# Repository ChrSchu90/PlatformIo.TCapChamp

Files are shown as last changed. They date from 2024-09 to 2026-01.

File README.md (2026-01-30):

# PlatformIo.TCapChamp


## Description
`ESP32` project that manipulates the outdoor air temperature measurement to adjust the heat pump cycle rate. In case the heat pump is over dimensioned it can increase its efficiency dramatically since you can adjust the cycle rate specifically on your environment and needs.
The manipulated temperature output needs to be connected to the external temperature sensor of the T-Cap.

If you already use an external temperature sensor you can connect it as input sensor for the ESP, in case you don't have a temperature sensor you can use the free [OpenWeather API](https://api.openweathermap.org) to receive actual temperatures. 

Via an optional 0-10V DAC it is also possible to limit the power consumption via `Demand Control` of the T-Cap.

> [!NOTE]
> You can find the measurements, charts and calculations inside the [TestsAndCharts.xlsx](Documentation/TestsAndCharts.xlsx),
> device specific information can be taken from the [T-Cap Service Manual (PDF)](https://web.archive.org/web/20250917183120/https://www.kaelte-bast.de/dateien_neu13/Panasonic/01-produktunterlagen/aquarea/produkte/waermepumpen/t-cap/sqc/handbuch_e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)

> [!TIP]
> Most important Manual pages:
> - 49 Wiring Connection Diagram
> - 53 Electronic Circuit Diagram
> - 56 Main Circuit Board 
> - 57 Sub Printed Circuit Board
> - 76 Cable management
> - 78 Temperature Sensor
> - 88 Demand Control
> - 128 Alternative Outdoor Ambient Sensor Control

> [!Caution]
> The connection between the T-Cap and the Controller should only be done by a trained professional. 
> **There is a danger to life due to high voltage (230V/400V) within the device!**

## Features
| Feature | Completed |
| --- | --- |
| Automatic switch between WiFi AP and Client mode | &#10003;  |
| Hardware sensor for input temperature | &#10003;  |
| Weather API for input temperature (OpenWeather) | &#10003;  |
| 0V-10V Demand control (Requires optional board) | &#10003;  |
| OTA Updates | &#10003;  |
| Captive Portal (if not working use IP `192.168.4.1`) | &#10003;  |
| Custom webinterface for better accessibility | &#10007;  |

## Bill of Material & Tools
| Name | Required | Description |
| --- | --- | --- |
| [ESP32 NodeMCU-32S](https://www.amazon.de/dp/B0CQSWC67G) | &#10003; | Microcontroller |
| [MCP4151-503E/P](https://agelektronik.de/digital-potentiometer/6459-mcp4151-503ep-digital-potentiometer50k256-steps1-kanalspidip-8.html) | &#10003; | Digital Potentiometer 50K, 256 steps, SPI |
| [Electrical wire 0.5mm² 20awg](https://www.amazon.de/dp/B08BZKR22W) | &#10003; | For bridges on custom Controller board |
| [Electrical wire 0.5mm² 20awg](https://www.amazon.de/dp/B0BJKHBW2Z) | &#10003; | For connection between bords and relay |
| [Electrical wire 18awg 2×0.75mm²](https://www.amazon.de/dp/B0B7WSMR8L) | &#10007; | Connection optional 0-10V Demand Control to T-Cap |
| [Electrical wire 18awg 4×0.75mm²](https://www.amazon.de/dp/B0BFWL2RZB) | &#10003; | Connection temperature output to T-Cap |
| [Prototype Board](https://www.amazon.de/dp/B08F2TS7ZC) | &#10003; | For final board |
| 10k resistor | &#10003; | Voltage divider for input sensor |
| 5k resistor | &#10003; | Pre-Resistor for Digital potentiometer (defines the possible output temperature, in my case +30°C to -20°C) |
| 2k resistor | &#10003; | GND pulldown for unused Digital potentiometer terminal |
| [4CH 5V Relay Module](https://www.amazon.de/dp/B09FS5G1Y9) | &#10007; | Optional relay module (High-Level-Trigger) for fallback implementation, not required but highly recommended!  |
| [DFRobot Gravity I2C DAC Module](https://www.dfrobot.com/product-2613.html) | &#10007; | Optional I2C DAC 0-10V for Demand Control |
| [Breadboard Kit](https://www.amazon.de/dp/B0B18G3V5T) | &#10007; | Prototype Board for testing |
| [Connectors](https://www.amazon.de/dp/B087RN8FDZ) | &#10007; | Connector for wires |
| [Socket for ESP](https://www.amazon.de/dp/B07DBY753C) | &#10007; | Socket for ESP |
| [IC Sockets](https://www.amazon.de/dp/B01GOLSUAU) | &#10007; | IC Socket for MCP4151 |

### Housing (example)
| Name | Description |
| --- | --- |
| [Housing](https://www.amazon.de/dp/B0CKT697NP) | Housing for Controller, Relay... |
| [USB-C Connector](https://www.amazon.de/dp/B0BQGBWVWM) | USB connector for power or PC |
| [4-Pin Connector Temperature](https://www.amazon.de/dp/B07TJK2Z7M) | Connector for temperature input/output  |
| [2-Pin Connector Demand Control](https://www.amazon.de/dp/B07JMYCPSN) | Connector for Demand control (optional) |
| [Mount for boards](https://www.amazon.de/dp/B09C21MS45) | Connector for Demand control (optional) |
| [Power Supply (USB-C)](https://www.amazon.de/dp/B07TMPC9FG) | External USB-C power supply |

### Tools
- Soldering iron, Solder...
- Multimeter
- Drill (for housing)
- Glue (for housing board mounts)

## Electrical Drawings
You can find the electrical drawings and parts inside `Documentation\Fritzing` as [Fritzing](https://fritzing.org/) (freeware) project.

### Without failover relay
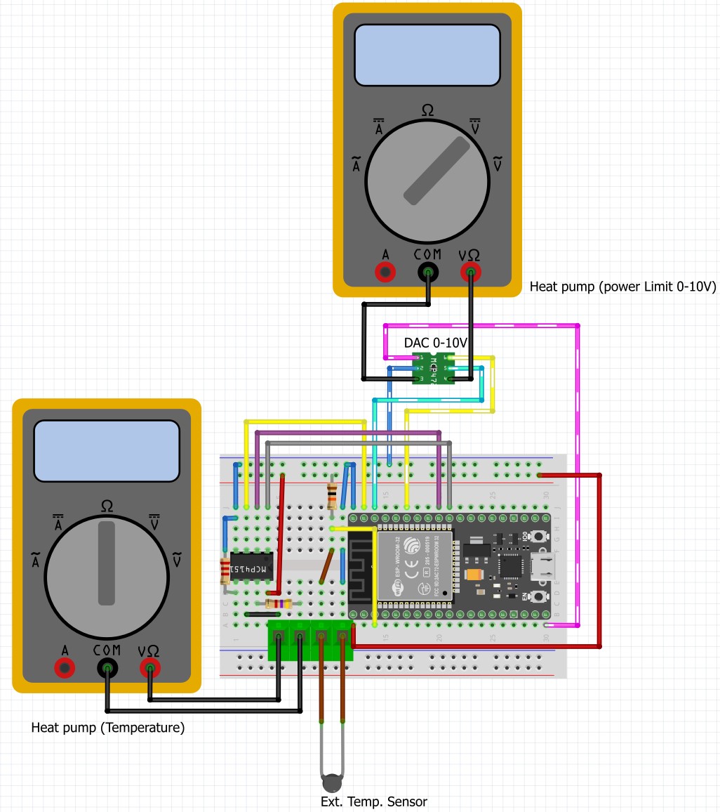
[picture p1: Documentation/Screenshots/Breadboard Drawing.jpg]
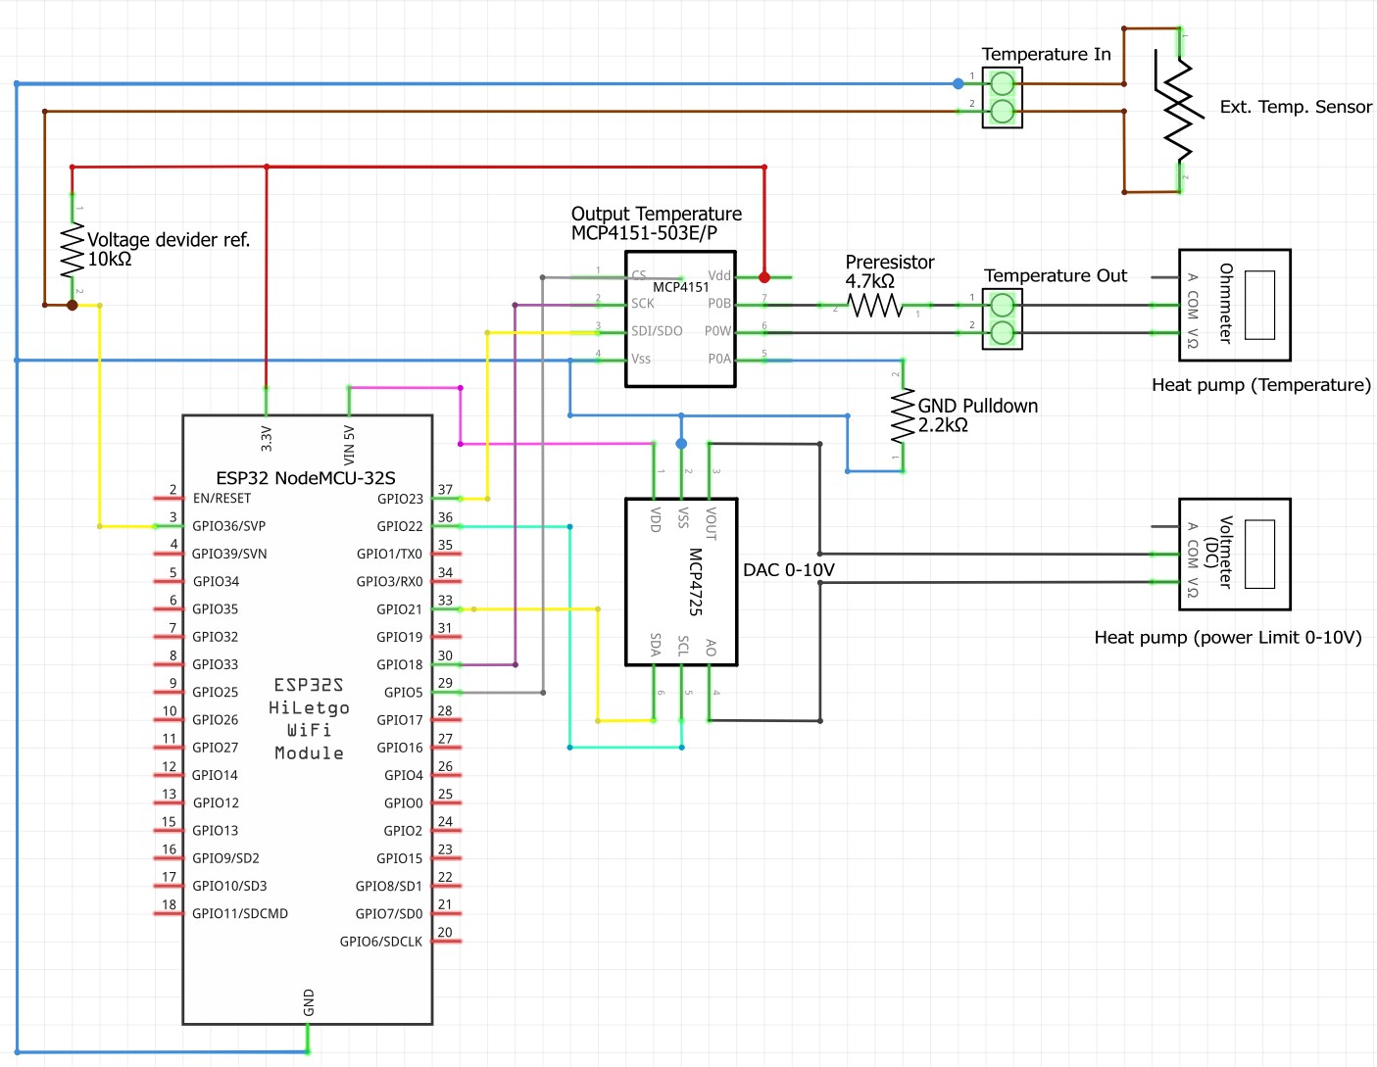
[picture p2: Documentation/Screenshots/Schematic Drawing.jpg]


### With failover relay (highly recommended)
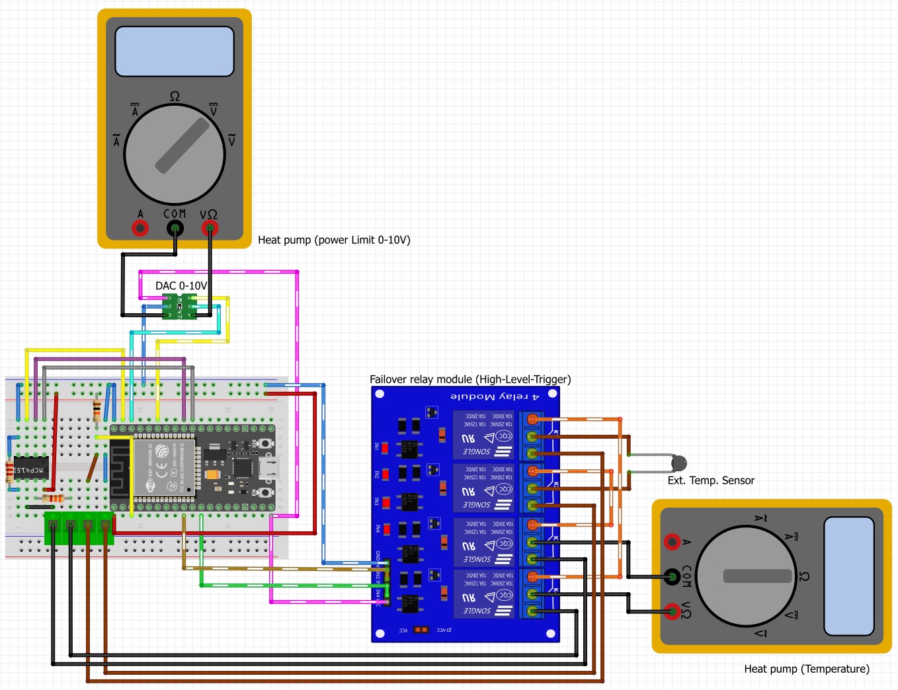
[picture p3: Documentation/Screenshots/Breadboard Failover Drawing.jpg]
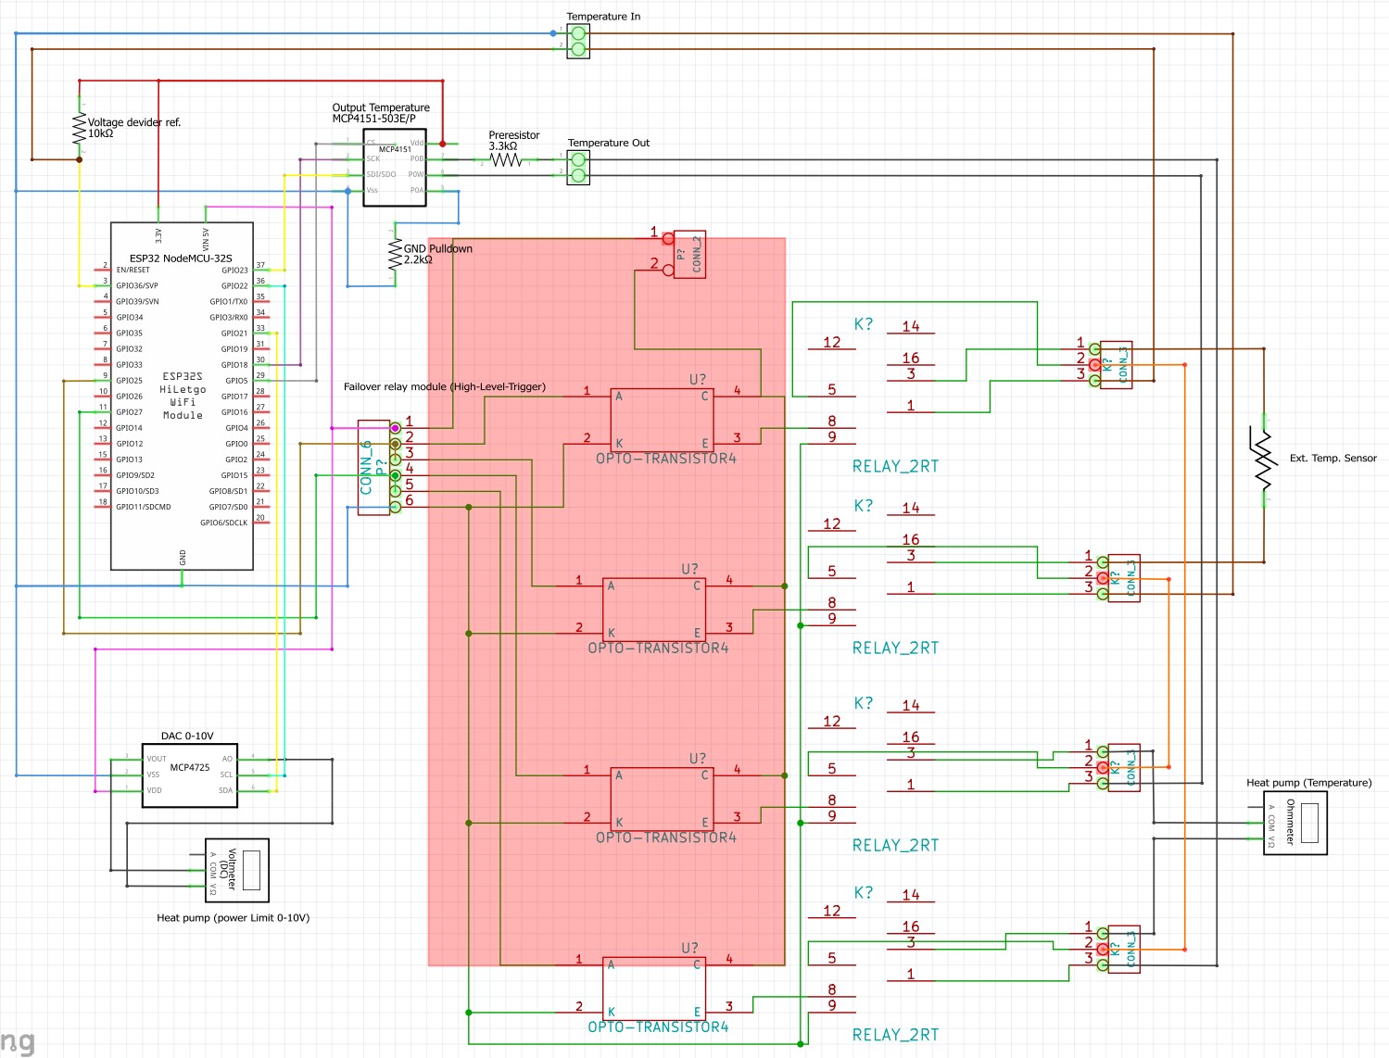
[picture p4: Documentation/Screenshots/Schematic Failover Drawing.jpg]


## Final board (example)
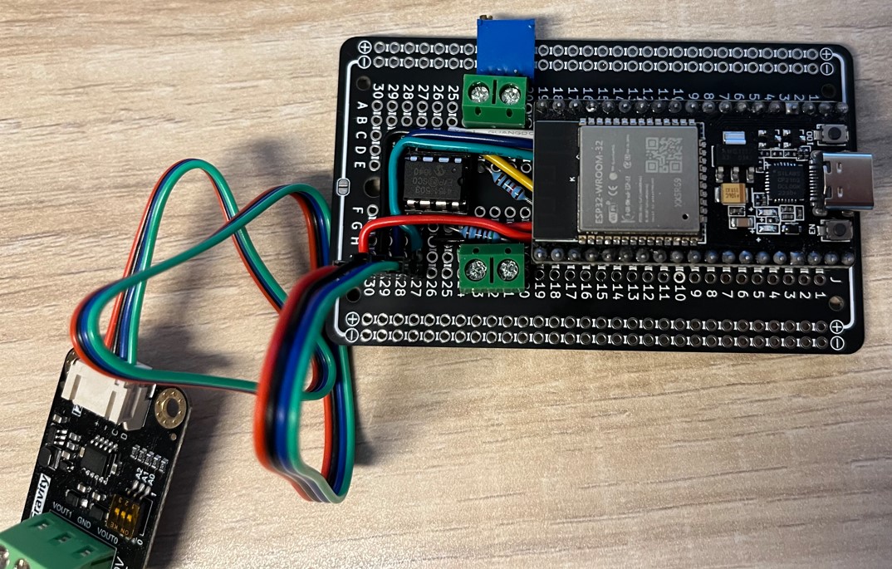
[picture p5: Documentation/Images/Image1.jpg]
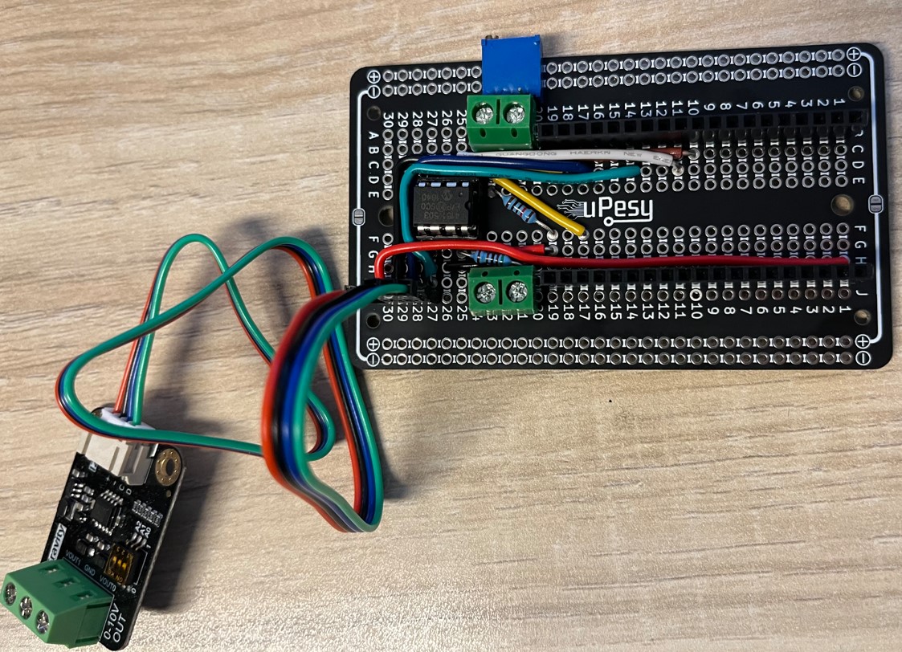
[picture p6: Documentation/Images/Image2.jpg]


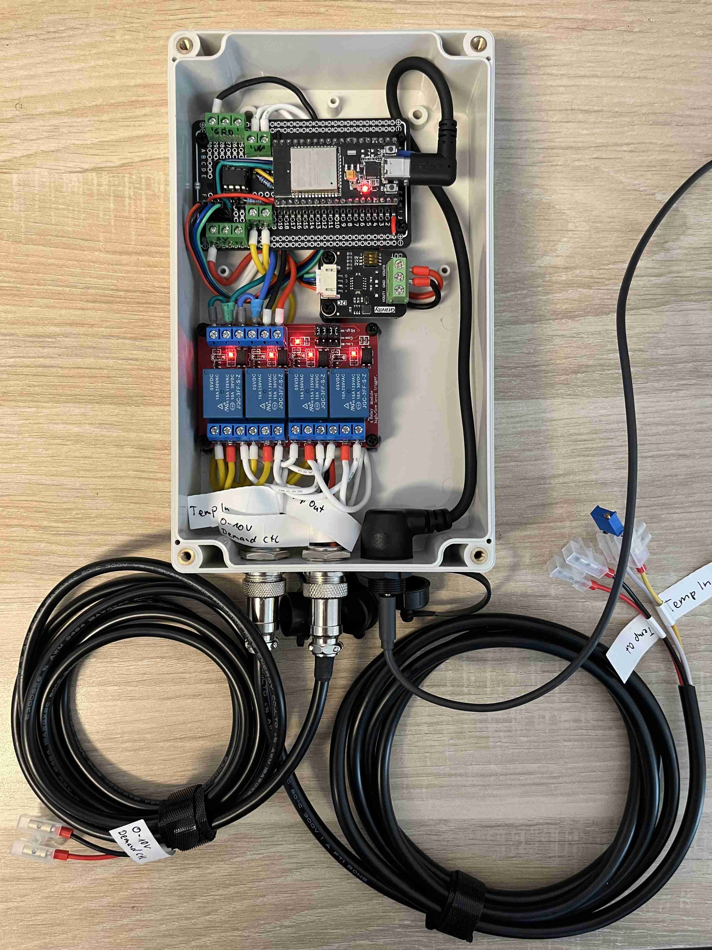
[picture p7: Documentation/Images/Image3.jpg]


## Webinterface
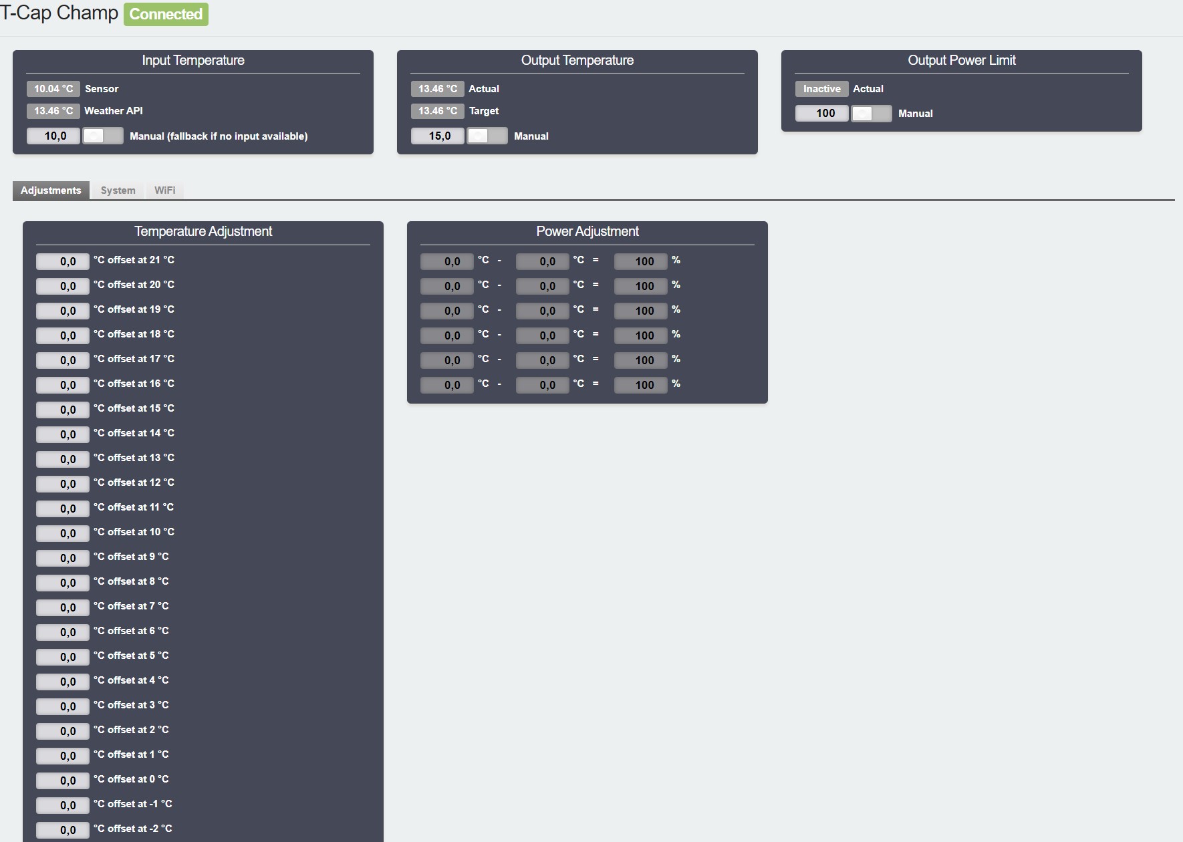
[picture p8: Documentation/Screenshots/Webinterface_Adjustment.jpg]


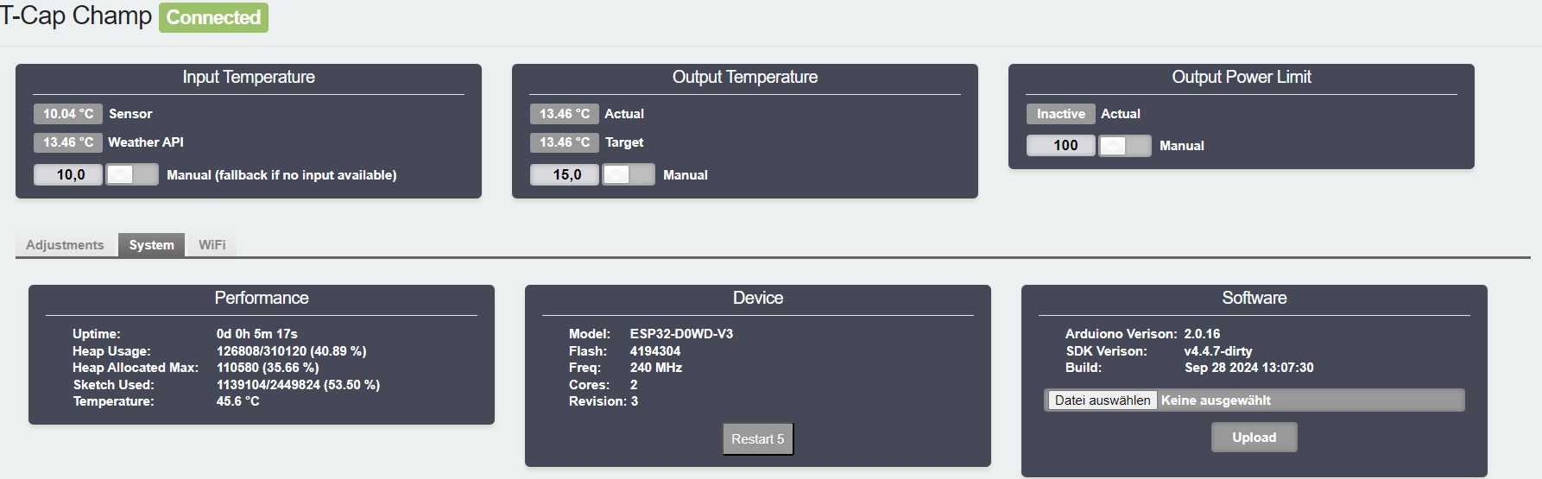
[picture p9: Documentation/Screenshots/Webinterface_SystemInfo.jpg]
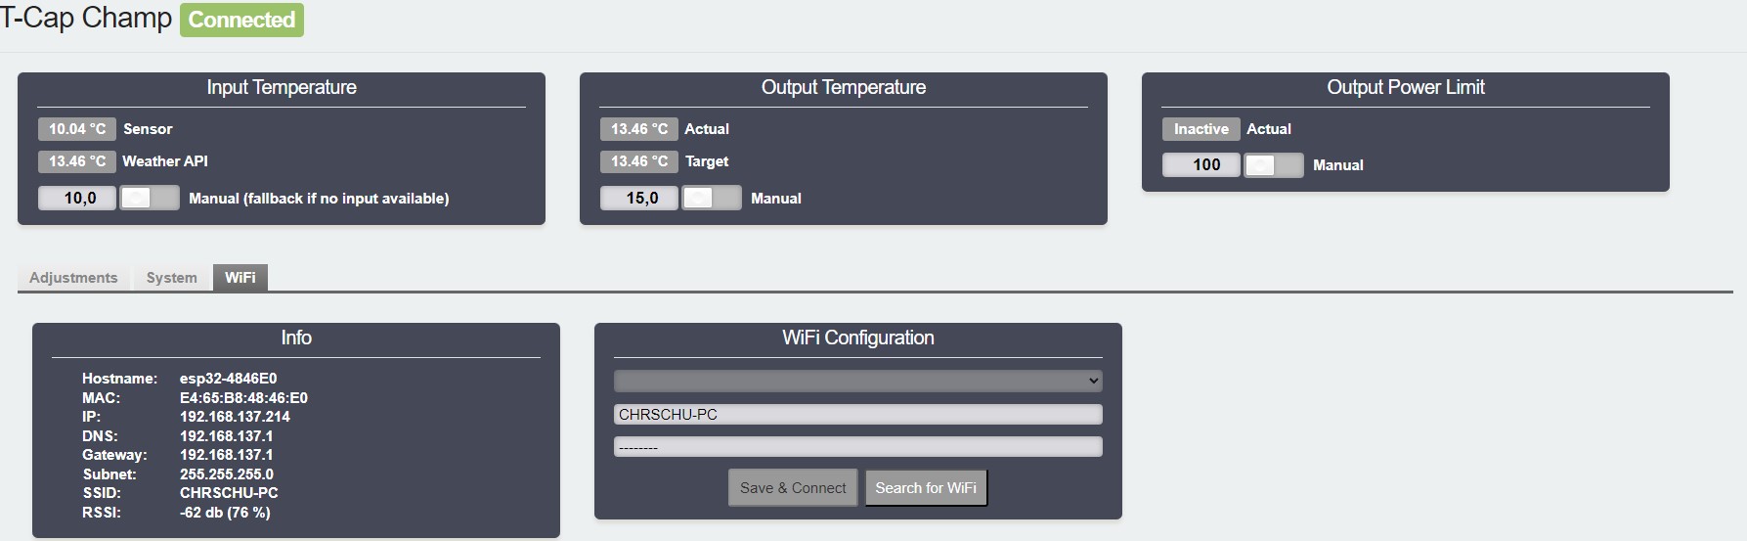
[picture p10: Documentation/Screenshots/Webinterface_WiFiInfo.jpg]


## Building the Project

> [!NOTE]
> This project requires [Visual Studio Code](https://code.visualstudio.com/download) with the 
> [PlatformIO IDE](https://marketplace.visualstudio.com/items?itemName=platformio.platformio-ide) and 
> [C/C++ Extension Pack](https://marketplace.visualstudio.com/items?itemName=ms-vscode.cpptools-extension-pack) extensions
> for compile and upload of the firmware to the Microcontroller.

> [!IMPORTANT]
> Make sure you have also installed the correct driver for the Microcontroller USB to Serial chip.
> Usually the driver is not part of the OS. In my case I needed to use the 
> [CP210x Universal Windows Driver](https://www.silabs.com/developers/usb-to-uart-bridge-vcp-drivers?tab=downloads)

For privacy reasons some settings are defined inside a header file that is excluded from git.
Since this information are used inside the classes copy and rename the file `Secrets.template.h` to `Secrets.h` to resolve build errors after cloning.

## Weather API
If there is no input sensor available you can use the integrated [OpenWeather API](https://openweathermap.org/current).
To do so you need to create a [free account](https://home.openweathermap.org/users/sign_up) to receive the required `API Key`.

The city ID can be taken from [OpenWeather](https://openweathermap.org) by searching for the location and can then be taken from URL `.../city/xxxxxxx`.
As alternative you can also use the `Latitude` + `Longitude` that can be taken from [Google Maps](https://www.google.com/maps) by right-click menu.

The configuration needs to be placed inside the `Secrets.h`.

> [!NOTE]
> Requests for free accounts are limited to to 60 calls/minute or 2000 calls/day

## Temperature Adjustment

### The cheap solution
A common way to manipulate the temperature is to connect a parallel resistor (e.g. 75kΩ) to the external sensor. The problem with this approach is that a thermal resistor isn't linear and because of that the temperature offset increases as the real temperature goes down:

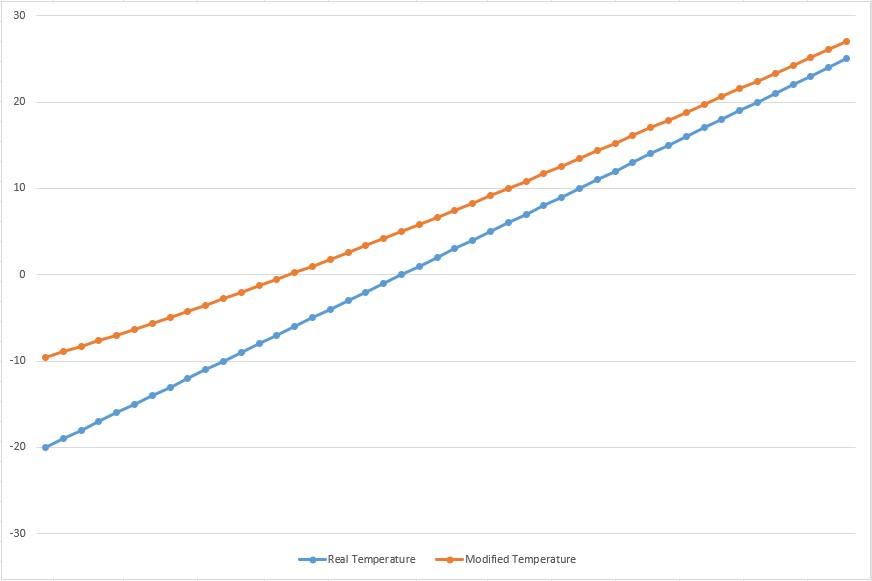
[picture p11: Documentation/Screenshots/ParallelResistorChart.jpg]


### The superior solution

### Temperature Adjustment
Due to the precision problems with a parallel resistor this project has been started, to provide a more granular and comfortable way, without changing hardware if another offset is required. 

It also makes it a lot easier at the beginning, since first you need to figure out what offset is the best based on your environment and preferences. To do so you can control input and output temperatures manually until you know where your sweet spot is. Afterwards the controller manipulates the output temperature based on a input temperature fully automated.

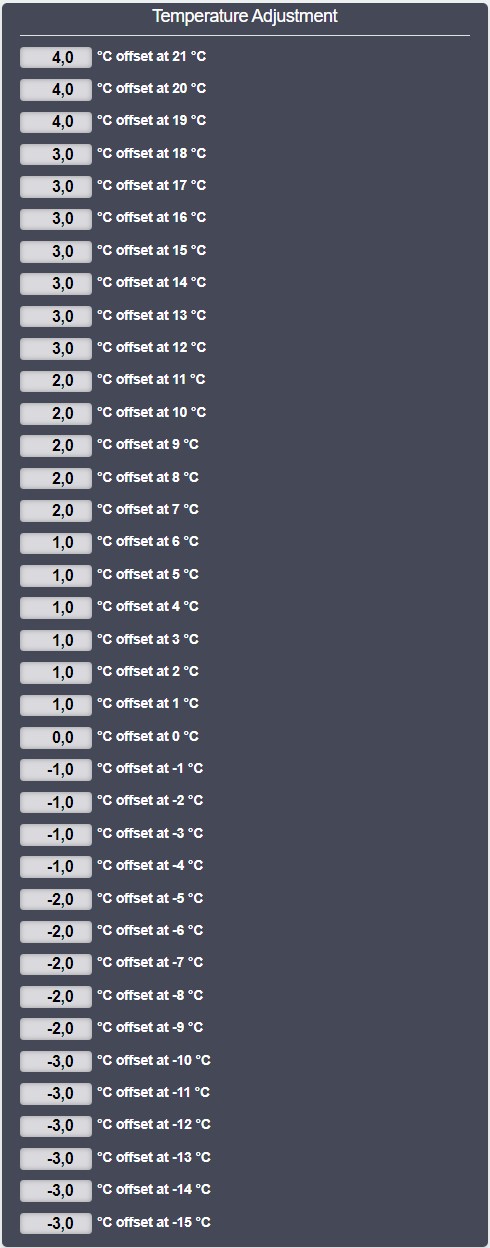
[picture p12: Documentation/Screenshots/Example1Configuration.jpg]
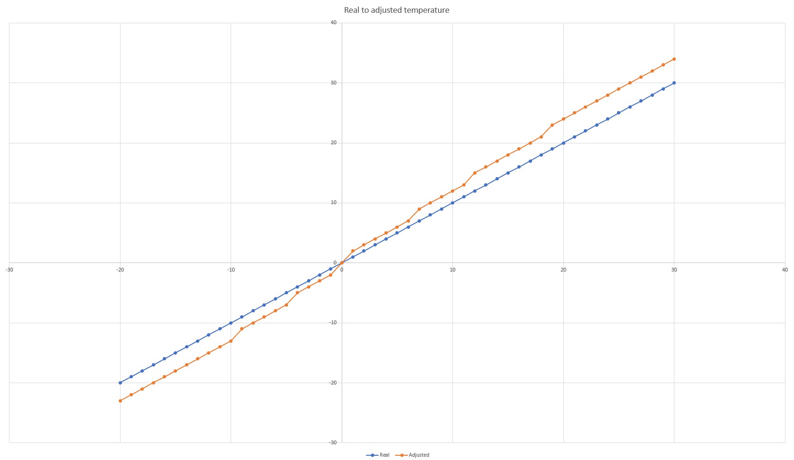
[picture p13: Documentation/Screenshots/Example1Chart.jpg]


### Input Temperature
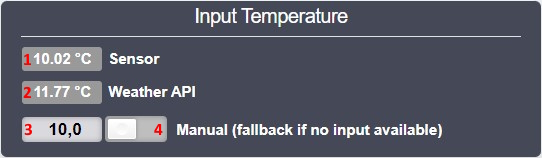
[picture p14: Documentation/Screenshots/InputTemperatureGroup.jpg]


1. Temperature from hardware sensor (`nan` if not connected)
2. Temperature received from the Weather API (`nan` if not configured)
3. Manual temperature input for testing (if `1` and `2` are `nan` value is used as fallback)
4. Force manual temperature `3` on/off

### Output Temperature
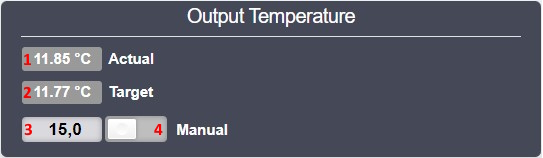
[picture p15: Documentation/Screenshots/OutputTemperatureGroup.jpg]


1. Actual output temperature (closest available to `2`, limited by the steps of the `Digital Potentiometer`)
2. Target temperature (input temperature + offset)
3. Manual output temperature for testing (ignores adjustment offsets)
4. Force manual output temperature `3` on/off

> [!IMPORTANT]
> Keep in mind that the components are not perfect and have tolerances. Also, the `Digital Potentiometer`
> works with limited steps, which can't always be on spot. 
> The `Target Temperature` is calculated and may not match the `Output Temperature` that represents the
> mathematically closest available resistance. If you want, you can use the T-Cap sensor calibration for compensation.
>
> Below you can find a chart with the delta between `Target Temperature`, `Output Temperature`
> and the measured output temperature that the T-Cap will read from the physical output resistance:
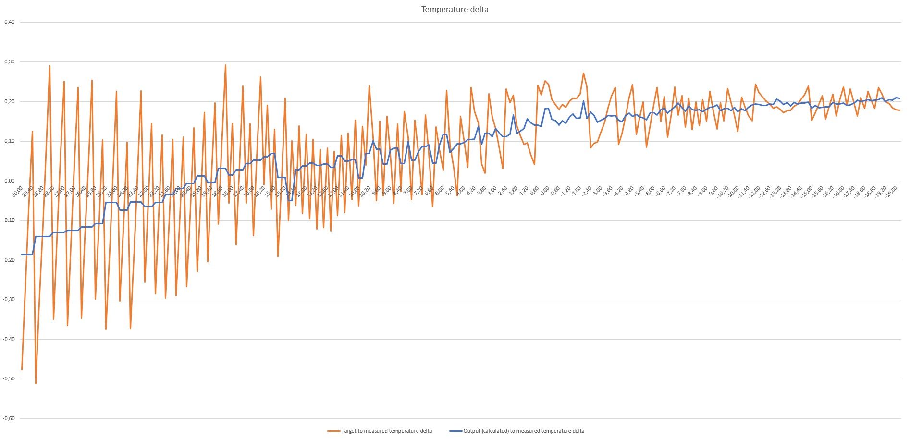
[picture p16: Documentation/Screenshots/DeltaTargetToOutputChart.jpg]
> 

## Demand Control (optional)
The T-Cap provides a 0-10V analog input to limit the power consumption. It can be a handy tool to optimize the heat pump even more as what is possible only by temperature adjustments.

To do so you can define temperature areas and its power limit inside the UI.

> [!NOTE]
> The `Input Temperature` will be used to determine the area, this ensures that 
> temperature adjustments will not influence the power limits.

> [!TIP]
> The first matching area will be uses (top to bottom). In case no responsible area will be found the output will be set to 0V (not active).
> If you like to define a default limit place the value inside the last area with start 30°C and end -20°C and define specific areas above. 
> To deactivate areas set start and end temperature to the same value.

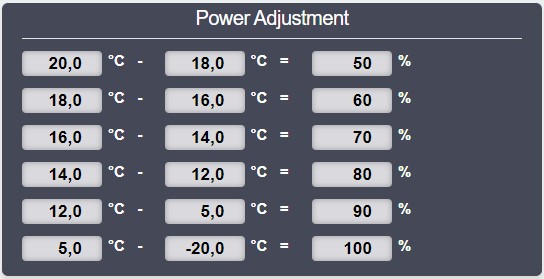
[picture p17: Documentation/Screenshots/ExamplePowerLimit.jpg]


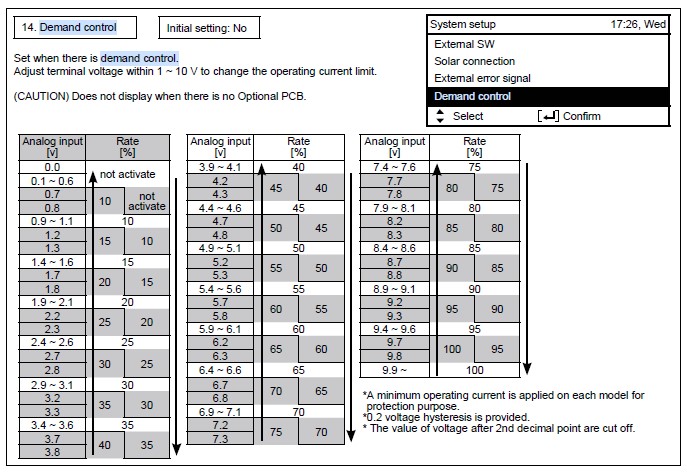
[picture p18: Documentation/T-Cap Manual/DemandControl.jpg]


### Output Power Limit


1. Actual power limit send to the T-Cap
2. Manual output power limit for testing (ignores adjustments)
3. Force manual output power limit `2` on/off

> [!NOTE]
> Power limit can be defined in a range between `10%-100%` in `5%` steps.
> Values `<10%` are handled as `not active`

## Wiring T-Cap

> [!Caution]
> The connection between the T-Cap and the Controller should only be done by a trained professional. 
> **There is a danger to life due to high voltage (230V/400V) within the device!**

> [!IMPORTANT]
> Please check the manual carefully to your specific device, this instruction is based on the `WH-SQC16H9E8`!
> In case you have another unit you might need to use other connectors within the device!

For all connection to the T-Cap I've used `0.75mm²`, you can also use another cable but **you need to use at least `0.3mm²`!**

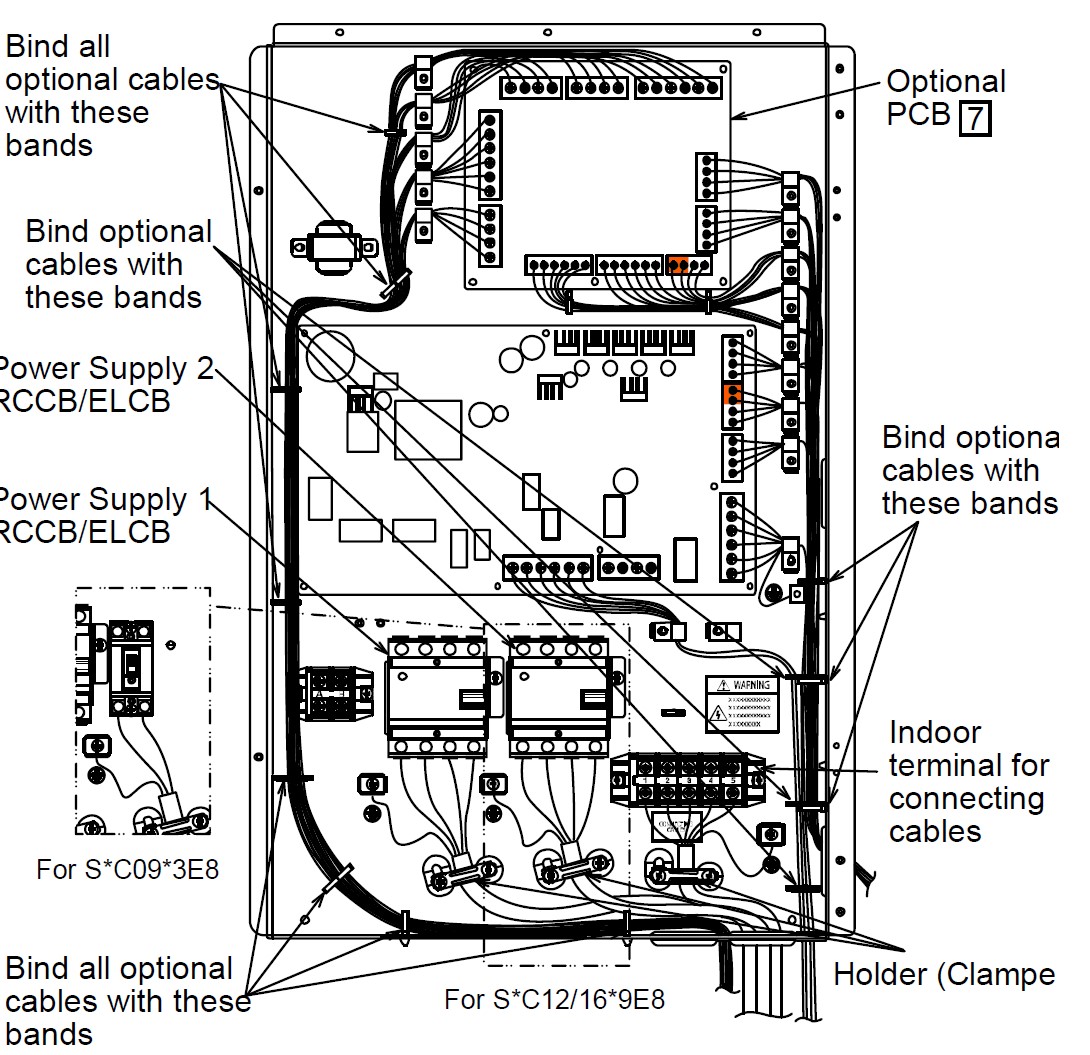
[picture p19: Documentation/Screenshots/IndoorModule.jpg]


### Temperature
If you already use a external temperature sensor, you should use it as input temperature for the controller.
In case you don't have an external sensor, you should connect a fallback resistor to simulate e.g. 10°C.

> [!TIP]
> Alternatively, you can also connect the temperature to the outdoor device instead of the indoor device.
> Make sure to check the manual for the correct wiring!

> [!NOTE]
> You need to change the setting of the T-Cap to use the alternative outdoor sensor, 
> otherwise, the temperature of the outdoor unit will be used.

> [!IMPORTANT]
> If there is no temperature sensor available for more than 5s the Device will notice it and log an error.
> Therefore, it is required to add a fallback resistor sensor if there is no real sensor connected to the controller.
> This is the reason why the fallback 4CH Relay Module is highly recommended, that will connect the input
> sensor to the T-Cap while the controller is turned off or during boot until it is ready!

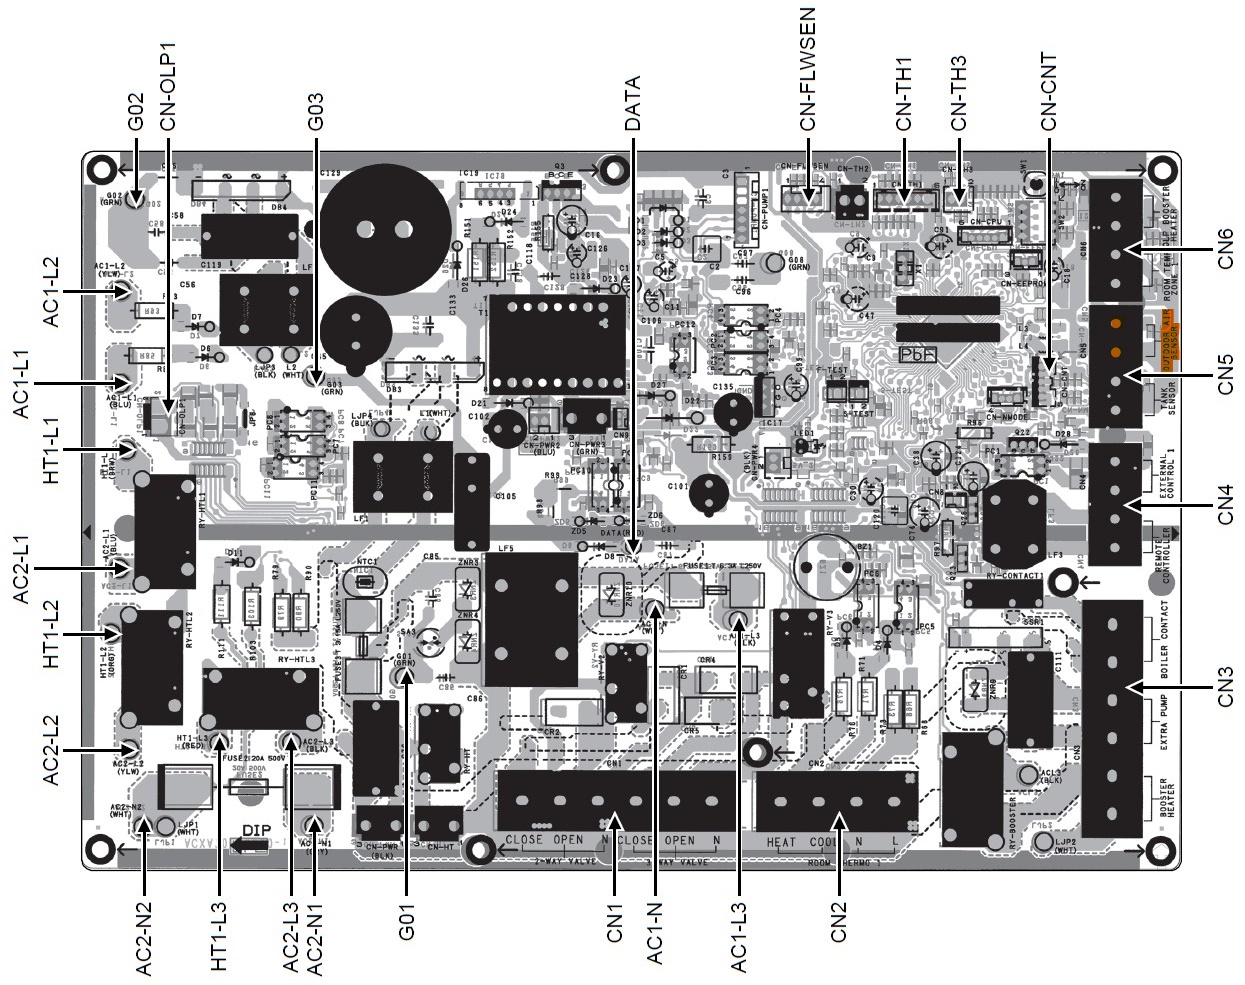
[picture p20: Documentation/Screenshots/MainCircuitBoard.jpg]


### Demand Control

> [!NOTE]
> The optional PCB needs to be available, needs to be enabled inside the T-Cap settings and the
> demand control needs to be enabled inside system settings.

> [!IMPORTANT]
> Make sure you have connected the 0-10V GND and 10V to the correct connectors, 
> unlike temperature it is important to pay attention to polarity!

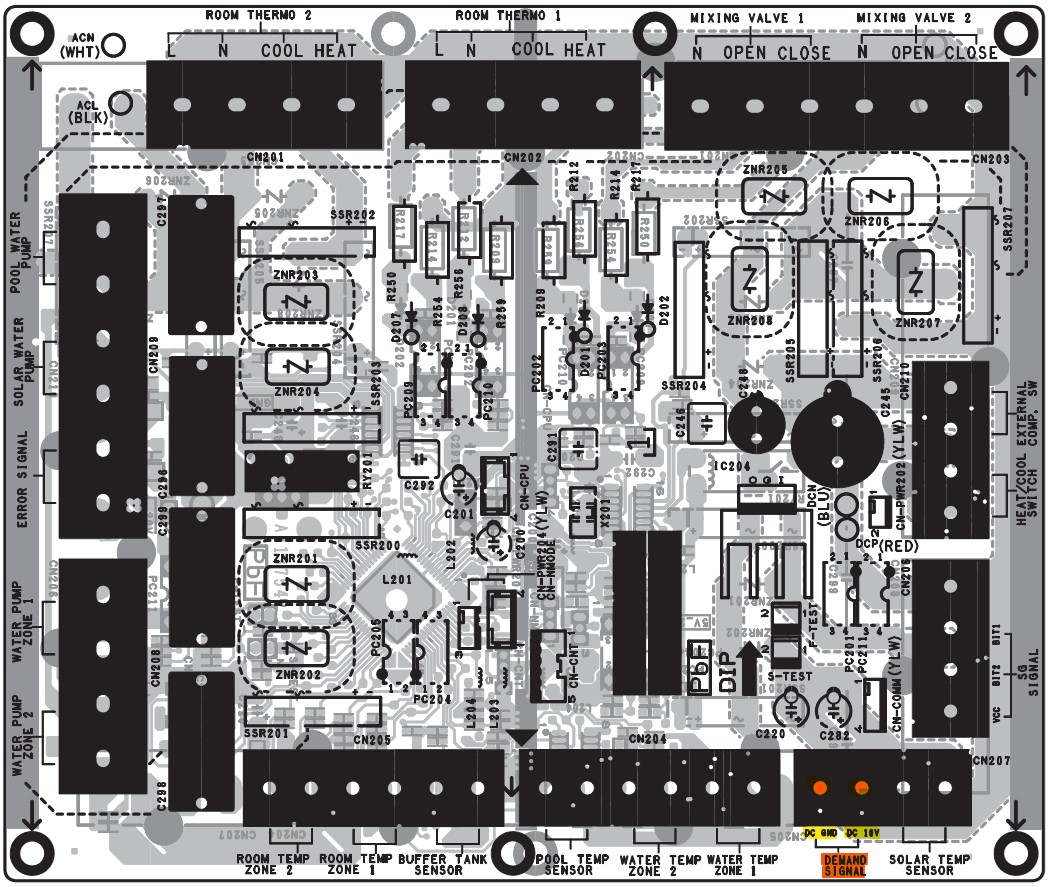
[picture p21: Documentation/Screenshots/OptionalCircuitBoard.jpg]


## 3rd Party libraries
The following libraries are used by this project (Thank you very much!)
- [ESPUI](https://github.com/s00500/ESPUI) for webinterface
- [RunningMedian](https://github.com/RobTillaart/RunningMedian) calculation for input temperature sensor
- [arduino-timer](https://github.com/contrem/arduino-timer) for time based functions
- [MycilaESPConnect](https://github.com/mathieucarbou/MycilaESPConnect) inspiration for WiFi AP/Client switching
- [ADC-Accuracy](https://github.com/G6EJD/ESP32-ADC-Accuracy-Improvement-function) ADC accuracy improvement
- [DFRobot_GP8403](https://github.com/DFRobot/DFRobot_GP8403) I2C DAC Module

## License
This project is licensed under [MIT license](LICENSE).

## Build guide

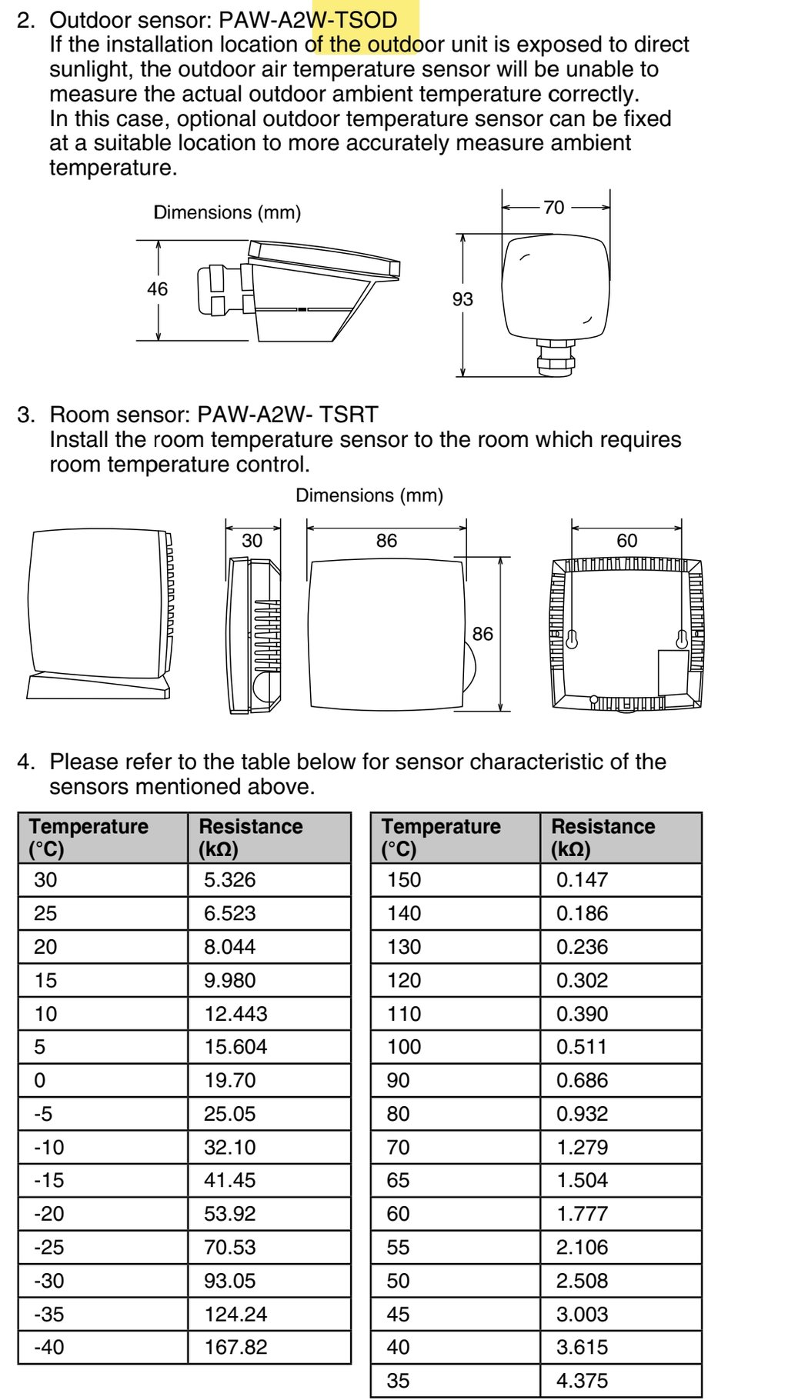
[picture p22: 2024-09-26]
Documentation/T-Cap Manual/TemperatureSensor.jpg

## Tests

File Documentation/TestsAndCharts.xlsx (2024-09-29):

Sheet: Temperature Output
Target Temp. | Output Temp. | Measured Res. | Measured Temp. | Delta Target-Output Temp. | Delta Measured-Output Temp. | Delta Target-Measured Temp.
30.00 | 29.71 | 5430 | 29.52 | -0.29 | -0.19 | -0.48
29.80 | 29.71 | 5430 | 29.52 | -0.09 | -0.19 | -0.28
29.60 | 29.71 | 5430 | 29.52 | 0.11 | -0.19 | -0.08
29.40 | 29.71 | 5430 | 29.52 | 0.31 | -0.19 | 0.12
29.20 | 28.83 | 5615 | 28.69 | -0.37 | -0.14 | -0.51
29.00 | 28.83 | 5615 | 28.69 | -0.17 | -0.14 | -0.31
28.80 | 28.83 | 5615 | 28.69 | 0.03 | -0.14 | -0.11
28.60 | 28.83 | 5615 | 28.69 | 0.23 | -0.14 | 0.09
28.40 | 28.83 | 5615 | 28.69 | 0.43 | -0.14 | 0.29
28.20 | 27.98 | 5808 | 27.85 | -0.22 | -0.13 | -0.35
28.00 | 27.98 | 5808 | 27.85 | -0.02 | -0.13 | -0.15
27.80 | 27.98 | 5808 | 27.85 | 0.18 | -0.13 | 0.05
27.60 | 27.98 | 5808 | 27.85 | 0.38 | -0.13 | 0.25
27.40 | 27.16 | 6003 | 27.04 | -0.24 | -0.12 | -0.36
27.20 | 27.16 | 6003 | 27.04 | -0.04 | -0.12 | -0.16
27.00 | 27.16 | 6003 | 27.04 | 0.16 | -0.12 | 0.04
26.80 | 27.16 | 6003 | 27.04 | 0.36 | -0.12 | 0.24
26.60 | 26.37 | 6197 | 26.25 | -0.23 | -0.12 | -0.35
26.40 | 26.37 | 6197 | 26.25 | -0.03 | -0.12 | -0.15
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

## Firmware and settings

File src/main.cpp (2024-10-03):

#define LOG_LEVEL NONE

#include <Arduino.h>
#include <arduino-timer.h>
#include <RunningMedian.h>
#include <SPI.h>
#include <Wire.h>
#include <DFRobot_GP8403.h>
#include "WiFiModeChamp.h"
#include "OpenWeatherMap.h"
#include "ThermistorCalc.h"
#include "Config.h"
#include "Webinterface.h"
#include "Secrets.h"
#include "SerialLogging.h"

static const uint8_t GPIO_THERMISTOR_IN = GPIO_NUM_36;										// GPIO used for real input temperature from thermistor
static const uint8_t SPI_BUS_THERMISTOR_OUT = VSPI;											// SPI bus used for digital potentiometer for output temperature
static const uint8_t GPIO_FAILOVER_OUT = GPIO_NUM_27;										// GPIO used as digital output to signal that the output temperature is now valid (failover via relays or LED)
static const uint8_t GPIO_FAILOVER_IN = GPIO_NUM_25;										// GPIO used as digital output to signal that the input temperature is now required (open failover via relays or LED)
static const float SUPPLY_VOLTAGE = 3.3;													// Maximum Voltage ADC input
static const unsigned int TEMP_IN_DEVIDER_RESISTANCE = 10000;								// Voltage divider resistor value for input temperature in Ohm
static const unsigned int TEMP_IN_SAMPLE_CYCLE = 10;										// Sample rate to build the median in milliseconds
static const unsigned int TEMP_IN_UPDATE_CYCLE = 1000;										// Update every n ms the input temperature
static const unsigned int TEMP_IN_SAMPLE_CNT = TEMP_IN_UPDATE_CYCLE / TEMP_IN_SAMPLE_CYCLE; // Amount of samples for input thermistor median calculation
static const unsigned int WEATHER_API_UPDATE_CYCLE = 600000;	   							// Update time of the temperture by the weather API in milliseconds
static const unsigned int WEATHER_API_UPDATE_CYCLE_FAILED = 10000; 							// Update time of the temperture by the weather API if the request has failed in milliseconds
static const bool PREFERE_WEATHER_API_OVER_INPUT_SENSOR = true;								// Defines that the Weather API has an higher preority than the real input temperature sensor
static const unsigned int TEMP_OUT_UPDATE_CYCLE = 1000;										// Update time of the output temperature in milliseconds
static const uint16_t DIGI_POTI_STEPS = 256;												// Maximum amount of steps that the digital potentiometer supports
static const uint16_t DIGI_POTI_STEP_MIN = 0;												// Minimum step of the digital potentiometer to limit maximum current (if no pre-resistor is used)
static const float DIGI_POTI_RESISTANCE = 50000.0f;											// Maximum resistance of the digital potentiometer in Ohm
static const float DIGI_POTI_PRERESISTANCE = 5000.0f;										// Digital potentiometer pre-resistor to limit current and improve precision in Ohm
static const unsigned int POWER_OUT_UPDATE_CYCLE = 1000; 									// Update time of the output temperature in milliseconds

ThermistorCalc _thermistorIn(-40, 167820, 25, 6523, 120, 302);	// Input for real temperature (Panasonic PAW-A2W-TSOD)
ThermistorCalc _thermistorOut(-40, 167820, 25, 6523, 120, 302); // Output that simulates a Panasonic PAW-A2W-TSOD for the Panasonic T-Cap
RunningMedian _thermistorInMedian(TEMP_IN_SAMPLE_CNT);			// Median average calculation for input temperature sensor
DFRobot_GP8403 *_i2cDac;										// DFRobot DAC for power limit (nullptr if not available)
SPIClass *_spiDigitalPoti;										// Digital potentiometer SPI interface
OpenWeatherMap *_weatherApi;									// OpenWeatherMap API access
Webinterface *_webinterface; 									// Access to the webinterface
Timer<6, millis> _timers;	 									// Timer collection for time based operations
Config *_config;			 									// Access to the configuration
float _thermistorInTemperature = NAN;							// Last temperature from input sensor (NAN if not available)
float _weatherApiTemperature = NAN;								// Last temperature from weather API (NAN if not available)
String _weatherApiTimestamp = emptyString;						// Last temperature from weather API (NAN if not available)
float _outputTemperature = NAN;									// Last output temperature (NAN if no temperature could be calculated)
float _targetTemperature = NAN;									// Last output target temperature (NAN if no temperature could be calculated)
uint8_t _powerLimitPercent = 0;									// Last powerlimit in percent (<10 means disabled)

/// @brief Reads the ADC voltage with none linear compensation (maximum reading 3.3V range from 0 to 4095)
float readAdcVoltageCorrected(uint8_t gpioPin)
{
	u_int16_t reading = analogRead(gpioPin);
	if (reading < 1)
	{
		return 0;
	}

	if (reading > 3757)
	{
		// From 3.0284V on we use the normal calculation, since the Polynomial curve will drift away and will never reach 3.3V (max out at 3.14V)
		return SUPPLY_VOLTAGE / 4095.0f * reading;
	}

	// Pre-calculated polynomial curve from https://github.com/G6EJD/ESP32-ADC-Accuracy-Improvement-function
	return -0.000000000000016 * pow(reading, 4) + 0.000000000118171 * pow(reading, 3) - 0.000000301211691 * pow(reading, 2) + 0.001109019271794 * reading + 0.034143524634089;
}

/// @brief Gets the current input thermistor temperature
/// @param logError Log detected errors due to e.g. unplausible values
/// @return the temperature of te input thermistor or NAN if there is no sensor conneted or if the value is unplausible
float getCurrentThermistorInTemperature(bool logError)
{
	float voltage = readAdcVoltageCorrected(GPIO_THERMISTOR_IN);
	if (!(voltage > 0))
	{
#ifdef LOG_ERROR
		if (logError)
			LOG_ERROR(F("Main"), F("getCurrentThermistorInTemperature"), F("Voltage unplausible, devider resistor defect? voltage=") + voltage);
#endif
		return NAN;
	}

	float resistance = TEMP_IN_DEVIDER_RESISTANCE * voltage / (SUPPLY_VOLTAGE - voltage);
	if (resistance == infinityf())
	{
#ifdef LOG_ERROR
		if (logError)
			LOG_ERROR(F("Main"), F("getCurrentThermistorInTemperature"), F("No external temperature sensor connected. resistance=") + resistance);
#endif
		return NAN;
	}

	return _thermistorIn.celsiusFromResistance(resistance);
}

/// @brief Update the _thermistorInTemperature by reading the input thermistor temperature to build a medain average
/// @return If the value has changed
bool updateThermistorInTemperature()
{
	float tempIn = getCurrentThermistorInTemperature(!isnanf(_thermistorInTemperature));
	if (isnanf(tempIn))
	{
		if (!isnanf(_thermistorInTemperature) || _thermistorInMedian.getCount() > 0)
		{
			_thermistorInMedian.clear();
			_thermistorInTemperature = NAN;
			return true;
		}

		return false;
	}

	_thermistorInMedian.add(tempIn);
	if ((_thermistorInMedian.getCount() % TEMP_IN_SAMPLE_CNT) == 0)
	{
		float medianTemp = _thermistorInMedian.getMedianAverage(TEMP_IN_SAMPLE_CNT);
		_thermistorInMedian.clear();
		if (isnanf(_thermistorInTemperature) || abs(medianTemp - _thermistorInTemperature) > 0.06)
		{
#ifdef LOG_INFO
			LOG_INFO(F("Main"), F("updateThermistorInTemperature"), F("Temperature (median) ") + medianTemp);
#endif
			_thermistorInTemperature = medianTemp;
			return true;
		}
	}

	return false;
}

/// @brief Update Weather API temperature timer callback
/// NOTE: The timer registration is handled by updateWeatherApiTemperature since
/// based on the API response the timer will be restarted with different ticks
bool updateWeatherApiTemperatureTick(void *opaque);

///	@brief Updates the _weatherApiTemperature via API
/// @return If the value has changed
bool updateWeatherApiTemperature()
{
	if (!_weatherApi)
	{
		return false;
	}

	auto request = _weatherApi->request();
	if (!request.successful)
	{
#ifdef LOG_ERROR
		switch (request.error)
		{
		case Error::WifiNotConnected:
			LOG_ERROR(F("Main"), F("updateWeatherApiTemperature"), F("Error on update temperature by weather API (WiFi not connected)"));
			break;
		case Error::HttpError:
			LOG_ERROR(F("Main"), F("updateWeatherApiTemperature"), F("Error on update temperature by weather API (HTTP error) ") + request.httpCode);
			break;
		case Error::DeserializationFailed:
			LOG_ERROR(F("Main"), F("updateWeatherApiTemperature"), F("Error on update temperature by weather API (Deserialization failed)"));
			break;
		}
#endif
		_timers.every(WEATHER_API_UPDATE_CYCLE_FAILED, updateWeatherApiTemperatureTick);
		return false;
	}

#ifdef LOG_INFO
	LOG_INFO(F("Main"), F("updateWeatherApiTemperature"), F("Updated temperature by weather API ") + request.temperature);
#endif

	_timers.every(WEATHER_API_UPDATE_CYCLE, updateWeatherApiTemperatureTick);
	bool changed = _weatherApiTemperature != request.temperature || _weatherApiTimestamp != request.timestamp;
	_weatherApiTemperature = request.temperature;
	_weatherApiTimestamp = request.timestamp;
	return changed;
}

/// @brief Update Weather API temperature timer callback
/// NOTE: The timer registration is handled by updateWeatherApiTemperature since
/// based on the API response the timer will be restarted with different ticks
bool updateWeatherApiTemperatureTick(void *opaque)
{
	if (updateWeatherApiTemperature() && _webinterface)
	{
		_webinterface->setWeatherTemp(_weatherApiTemperature, _weatherApiTimestamp);
	}

	// Stop current timer, a new one is created by updateWeatherApiTemperature depending if failed or successful
	return false;
}

/// @brief Gets the real input temperature that is used to calculate the power limit and output temperature
/// @attention Priority: 1st Nanual Temperature, 2nd Weather API, 3rd fallback to Nanual Temperature and NAN if it is not possible to determine a input temperature
/// @return The input temperature or NAN if it is not possible to determine one
float getInputTemperature()
{
	// Use manual temperature as highest priority
	if (_config->temperatureConfig->isManualInputTemp()) 
		return _config->temperatureConfig->getManualInputTemperature();
	// Use Weather API as preferred input by static setting
	if (PREFERE_WEATHER_API_OVER_INPUT_SENSOR && !isnanf(_weatherApiTemperature)) 
		return _weatherApiTemperature;
	// Use real temperature sensor if Weather API is not preferred by static setting
	if (!isnanf(_thermistorInTemperature)) 
		return _thermistorInTemperature;
	// Use Weather API
	if (!isnanf(_weatherApiTemperature)) 
		return _weatherApiTemperature;
	
	// Use the manual temperature as fallback if no API or input sensor value is available
	return _config->temperatureConfig->getManualInputTemperature();
}

/// @brief Updates the _outputTemperature based on getInputTemperature()
/// @return If the value has changed
bool updateOutputTemperature()
{
	float inputTemperature = getInputTemperature();
	_targetTemperature = _config->temperatureConfig->getOutputTemperature(inputTemperature);

	bool changed = false;
	if (!isnanf(_targetTemperature))
	{
		float targetResistance = _thermistorOut.resistanceFromCelsius(_targetTemperature);
		uint16_t posistion = targetResistance >= DIGI_POTI_PRERESISTANCE ? roundf(((targetResistance - DIGI_POTI_PRERESISTANCE) / (DIGI_POTI_RESISTANCE / (DIGI_POTI_STEPS + 1))) - 1) : 0;
		posistion = constrain(posistion, DIGI_POTI_STEP_MIN, DIGI_POTI_STEPS);
		float positionResistance = (DIGI_POTI_RESISTANCE / (DIGI_POTI_STEPS + 1)) + (posistion * (DIGI_POTI_RESISTANCE / (DIGI_POTI_STEPS + 1)));
		float outputResistance = DIGI_POTI_PRERESISTANCE + positionResistance;
		float outputTemperature = _thermistorOut.celsiusFromResistance(outputResistance);
		if (_outputTemperature != outputTemperature)
		{
#ifdef LOG_DEBUG
			LOG_DEBUG(F("Main"), F("updateOutputTemperature"), F("targetTemp=") + String(_targetTemperature) + F(" targetResistance=") + String(targetResistance) + F(" posistion=") + String(posistion) + F(" positionResistance=") + String(positionResistance) + F(" outputResistance=") + String(outputResistance) + F(" outputTemperature=") + String(outputTemperature));
#endif
			_spiDigitalPoti->transfer16(posistion);
			_outputTemperature = outputTemperature;
			changed = true;
		}
	}
	else
	{
		changed = !isnanf(_outputTemperature);
		_outputTemperature = _targetTemperature;
	}

	digitalWrite(GPIO_FAILOVER_OUT, !isnanf(_outputTemperature) ? HIGH : LOW);
	return changed;
}

/// @brief Sets the powerlimit via DAC 0-10V, updates the _powerLimitPercent and webinterface
/// @attention T-Cap need at least a 10% power limit, less is detected as disabled demand control
/// @param percent The new power limit in %
/// @param force Force sending the given value to the DAC
/// @return true if the limit has been changed, otherwise false
bool setPowerLimit(uint8_t percent, bool force = false)
{
	percent = min(max(percent, (uint8_t)MIN_POWER_LIMIT), (uint8_t)MAX_POWER_LIMIT);
	if (!_i2cDac || (!force && percent == _powerLimitPercent))
	{
		return false;
	}

	_i2cDac->setDACOutVoltage(percent * 100, 0); // percent to mV on CH0
	// delay(1000); // wait before store, due to exceptions
	// dac.store(); // save value?
	_powerLimitPercent = percent;
#ifdef LOG_DEBUG
	LOG_DEBUG(F("Main"), F("setPowerLimit"), F("Set power limit to ") + String(_powerLimitPercent) + "%");
#endif
	if (_webinterface)
	{
		_webinterface->setOuputPowerLimit(_powerLimitPercent);
	}

	return true;
}

/// @brief Put your main code here, to run repeatedly:
void loop()
{
	_timers.tick();
	WifiModeChamp.loop();
}

/// @brief Setup for Weather API with blocking initial request
void setupWeatherApi()
{
#ifdef LOG_DEBUG
	LOG_DEBUG(F("Main"), F("setupWeatherApi"), F("Started"));
#endif
	auto apiKey = String(WEATHER_API_KEY);
	if (apiKey.length() < 30)
	{
#ifdef LOG_ERROR
		LOG_ERROR(F("Main"), F("setupWeatherApi"), F("API key missing or invalid, weather API can't be used!"));
#endif
		return;
	}

	if (WEATHER_CITY_ID > 0)
	{
#ifdef LOG_INFO
		LOG_INFO(F("Main"), F("setupWeatherApi"), F("Using City ID ") + WEATHER_CITY_ID);
#endif
		_weatherApi = new OpenWeatherMap(apiKey, WEATHER_CITY_ID);
	}
	else if (abs(WEATHER_LATITUDE) > 0 && abs(WEATHER_LONGITUDE) > 0)
	{
#ifdef LOG_INFO
		LOG_INFO(F("Main"), F("setupWeatherApi"), F("Using Latitude ") + WEATHER_LATITUDE + F(" and Longitude ") + WEATHER_LONGITUDE);
#endif
		_weatherApi = new OpenWeatherMap(apiKey, WEATHER_LATITUDE, WEATHER_LONGITUDE);
	}
	else
	{
#ifdef LOG_ERROR
		LOG_ERROR(F("Main"), F("setupWeatherApi"), F("Location missing, please define CityID or Latitude + Longitude!"));
#endif
		return;
	}
#ifdef LOG_DEBUG
	LOG_DEBUG(F("Main"), F("setupWeatherApi"), F("API URL ") + _weatherApi->apiUrl);
#endif
	if (updateWeatherApiTemperature())
	{
#ifdef LOG_INFO
		LOG_INFO(F("Main"), F("setupWeatherApi"), F("initial temperature ") + _weatherApiTemperature);
#endif
	}
}

/// @brief Setup reading of input thermistor with blocking initial reading
void setupThermistorInputReading()
{
#ifdef LOG_DEBUG
	LOG_DEBUG(F("Main"), F("setupThermistorInputReading"), F("Started"));
#endif

	// Configure failover output pin an enable it 
	pinMode(GPIO_FAILOVER_IN, OUTPUT);
	digitalWrite(GPIO_FAILOVER_IN, HIGH);

	delay(100); // Wait a littlebit of time after relai has been turned on, so we can read initial temperature
	_thermistorInTemperature = getCurrentThermistorInTemperature(true);
#ifdef LOG_DEBUG
	LOG_DEBUG(F("Main"), F("setupThermistorInputReading"), F("Inital in termperature=") + _thermistorInTemperature);
#endif
	_timers.every(
		TEMP_IN_SAMPLE_CYCLE,
		[](void *opaque) -> bool
		{
			if (updateThermistorInTemperature() && _webinterface)
			{
				_webinterface->setSensorTemp(_thermistorInTemperature);
			}

			return true; // Keep timer running
		});

#ifdef LOG_DEBUG
	LOG_DEBUG(F("Main"), F("setupThermistorInputReading"), F("Completed"));
#endif
}

/// @brief Setup digital potentiometer for output temperature with blocking initial update of output temperature
void setupOutputTemperature()
{
#ifdef LOG_DEBUG
	LOG_DEBUG(F("Main"), F("setupOutputTemperature"), F("Started"));
#endif

	_spiDigitalPoti = new SPIClass(SPI_BUS_THERMISTOR_OUT);
	//_spiDigitalPoti->setClockDivider(SPI_CLOCK_DIV4); // Default SPI_CLOCK_DIV16 (1 MHz)
	_spiDigitalPoti->begin();
	pinMode(_spiDigitalPoti->pinSS(), OUTPUT);
	pinMode(GPIO_FAILOVER_OUT, OUTPUT);

	updateOutputTemperature();
	_timers.every(
		TEMP_OUT_UPDATE_CYCLE,
		[](void *opaque) -> bool
		{
			if (_webinterface)
			{
				auto oldTargetTemp = _targetTemperature;
				if(updateOutputTemperature())
					_webinterface->setOutputTemp(_outputTemperature);
				
				if(oldTargetTemp != _targetTemperature)
					_webinterface->setTargetTemp(_targetTemperature);

				_webinterface->updateSystemInformation();
			}

			return true;
		});
#ifdef LOG_DEBUG
	LOG_DEBUG(F("Main"), F("setupOutputTemperature"), F("Completed"));
#endif
}

/// @brief Setup of the power limiter via 0-10V analog output
void setupPowerLimit()
{
#ifdef LOG_DEBUG
	LOG_DEBUG(F("Main"), F("setupPowerLimit"), F("Started"));
#endif

	auto dac = new DFRobot_GP8403(&Wire, 0x5F);
	if (dac->begin() != 0)
	{
#ifdef LOG_ERROR
		LOG_ERROR(F("Main"), F("setupPowerLimit"), F("Error on init 0-10V output via I2C!"));
#endif
	}
	else
	{
		_i2cDac = dac;
		_i2cDac->setDACOutRange(dac->eOutputRange10V);
#ifdef LOG_DEBUG
		LOG_DEBUG(F("Main"), F("setupPowerLimit"), F("Successful init 0-10V output via I2C"));
#endif
		setPowerLimit(_powerLimitPercent, true); // initially set to 0% (disable power limit)
		_timers.every(
			POWER_OUT_UPDATE_CYCLE,
			[](void *opaque) -> bool
			{
				auto inputTemperature = getInputTemperature();
				auto powerLimit = _config->powerConfig->getOutputPowerLimit(inputTemperature);
				if (setPowerLimit(powerLimit) && _webinterface)
				{
					_webinterface->setOuputPowerLimit(_powerLimitPercent);
				}

				return true;
			});
	}
}

/// @brief Setup for the configuration for loading and storing none volatile data
void setupConfiguration()
{
#ifdef LOG_DEBUG
	LOG_DEBUG(F("Main"), F("setupConfiguration"), F("Started"));
#endif

	_config = new Config();

#ifdef LOG_DEBUG
	LOG_DEBUG(F("Main"), F("setupConfiguration"), F("Completed"));
#endif
}

/// @brief Setup for Web UI (called by setupWifiManager after auto connect)
void setupWebinterface()
{
#ifdef LOG_DEBUG
	LOG_DEBUG(F("Main"), F("setupWebinterface"), F("Started"));
#endif

	// Creaate webinterface
	_webinterface = new Webinterface(80, _config);

	// Set initial values
	_webinterface->setSensorTemp(_thermistorInTemperature);
	_webinterface->setWeatherTemp(_weatherApiTemperature, _weatherApiTimestamp);
	_webinterface->setOutputTemp(_outputTemperature);
	_webinterface->setTargetTemp(_targetTemperature);
	if (_i2cDac)
	{
		_webinterface->setOuputPowerLimit(_powerLimitPercent);
	}
	else
	{
		_webinterface->setOuputPowerLimit(NAN);
	}

#ifdef LOG_DEBUG
	LOG_DEBUG(F("Main"), F("setupWebinterface"), F("Completed"));
#endif
}

/// @brief Setup for WiFiManager as blocking implementation if configured.
void setupWifiManager()
{
#ifdef LOG_DEBUG
	LOG_DEBUG(F("Main"), F("setupWifiManager"), F("Started"));
	WifiModeChamp.listen(
		[](__unused WifiModeChampState previous, WifiModeChampState state)
		{
			LOG_DEBUG(F("Main"), F("WifiModeChamp.listen"), F("State changed from ") + WifiModeChamp.getStateName(previous) + F(" to ") + WifiModeChamp.getStateName(state));
		});
#endif

	WifiModeChamp.setReconnectTimeout(120);
    WifiModeChamp.setConnectTimeout(30);
    WifiModeChamp.setWifiScanWaitTime(30);
	WifiModeChamp.begin("T-Cap Champ", true, WIFI_CONFIG_PASSWORD);
}

/// @brief Put your setup code here, to run once:
void setup()
{
	Serial.begin(115200);

#ifdef LOG_ERROR
	delay(3000);
#endif
#ifdef LOG_DEBUG
	LOG_DEBUG(F("Main"), F("setup"), F("Started"));
#endif

	setupConfiguration();
	setupWifiManager();
	setupWeatherApi();
	setupPowerLimit();
	setupThermistorInputReading();
	setupOutputTemperature();
	setupWebinterface();

#ifdef LOG_DEBUG
	LOG_DEBUG(F("Main"), F("setup"), F("Completed"));
#endif
}

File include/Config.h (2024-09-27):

#pragma once

#include <Preferences.h>

#define MIN_TEMPERATURE -20                                 // Minimum supported temperature in °C
#define MAX_TEMPERATURE 30                                  // Maximum supported temperature in °C
#define ADJUST_TEMP_START 21                                // Start of adjustment temperatures in °C
#define ADJUST_TEMP_END -15                                 // End of adjustment temperatures in °C
#define ADJUST_TEMP_MAX_OFSET 10                            // Maximum offset adjustment temperature in °C
#define KEY_SETTINGS_NAMESPACE "TCapChamp"                  // Preferences namespance key (limited to 15 chars)
#define KEY_SETTING_TEMP_MANUAL_OUT_MODE "TempOutManual"    // Preferences key for manual output temperature mode (limited to 15 chars)
#define KEY_SETTING_TEMP_MANUAL_OUT_TEMP "ManualOutTemp"    // Preferences key for manual output temperature (limited to 15 chars)
#define KEY_SETTING_TEMP_MANUAL_IN_MODE "TempInManual"      // Preferences key for manual input temperature mode (limited to 15 chars)
#define KEY_SETTING_TEMP_MANUAL_IN_TEMP "ManualInTemp"      // Preferences key for manual input temperature (limited to 15 chars)
#define KEY_SETTING_TEMP_ADJUST_TEMP_OFFSET "TempOffset"    // Preferences key for temperature offset NOTE: WITHOUT INDEX (limited to 15 chars)

#define MIN_POWER_LIMIT 0                             // Minimum supported power limit in %
#define MAX_POWER_LIMIT 100                           // Maximum supported power limit in %
#define STEP_POWER_LIMIT 5                            // Setps supported by the power limit in %
#define KEY_SETTING_POWER_MANUAL_MODE "PowerManual"   // Preferences key for manual power mode (limited to 15 chars)
#define KEY_SETTING_POWER_MANUAL_POWER "ManualPower"  // Preferences key for manual power (limited to 15 chars)
#define KEY_SETTING_POWER_AREA_START "PowerStart"     // Preferences key area start temperature NOTE: WITHOUT INDEX
#define KEY_SETTING_POWER_AREA_END "PowerEnd"         // Preferences key area end temperature NOTE: WITHOUT INDEX
#define KEY_SETTING_POWER_AREA_LIMIT "PowerLimit"     // Preferences key area power limit NOTE: WITHOUT INDEX

static const size_t TEMP_ADJUST_AMOUNT = abs(ADJUST_TEMP_END - ADJUST_TEMP_START) + 1; // The amount of temperature adjustments based on ADJUST_TEMP_START and ADJUST_TEMP_END
static const size_t POWER_AREA_AMOUNT = 6;          // Amount of power areas

class TemperatureArea;
class PowerArea;

/// @brief Defines an adjustment for a specific temperature
class TemperatureAdjustment
{
private:
    Preferences *_preferences;    
    float _tempOffset;          // Temperature offset

protected:
public:
    const int8_t tempReal;      // Real measured temperature

    /// @brief Creates a new instance of an TemperatureConfig
    /// @param preferences the app preferences to stroe the configuration
    TemperatureAdjustment(int8_t tempReal, Preferences *preferences);

    /// @brief Gets the adjusted temperature
    float getTemperatureAdjusted() { return tempReal + _tempOffset; };

    /// @brief Gets the temperature offset
    float getTemperatureOffset() { return _tempOffset; };

    /// @brief Sets the temperature offset to calculate the adjusted temperature
    /// @param offset the new offset
    /// @return the saved temperature offset after limit checks
    float setTemperatureOffset(float offset);
};

/// @brief Holds the temperature configuration
class TemperatureConfig
{
private:
    TemperatureAdjustment *_adjustments[TEMP_ADJUST_AMOUNT];
    Preferences *_preferences;
    bool _manualOutputActive;
    bool _manualInputActive;
    float _manualOutputTemperature;
    float _manualInputTemperature;
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

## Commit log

2024-03-16 Create project and add calculation for thermistor
2024-03-21 Setup weather API with secrets and read temperature from ADC with linear compensation and median
2024-03-23 Refactoring and MCP4151 with SPI implementation
2024-03-24 Bugfix in debug log
    [main.cpp]
2024-03-25 Renamed project, improved output temperature calculation and start to separate OpenWeatherMap into class
2024-03-26 Switch from ESP-DASH to ESPUI due to limitations
2024-03-27 Implement Web UI tabs for System and WiFi info with buttos to reset WiFi config and reboot of device.
    [main.cpp]
2024-05-29 Test implementation for 0-10V DAC output for power limitation
2024-06-04 Refactoring and bugfix inside ESPUI that lead into memory issues
    [Webinterface.h, main.cpp]
2024-06-07 Add Fritzing parts and projects and updated libraries
    [TCapChamp.fzz, TCapChamp_Failover.fzz]
2024-06-15 Start power limit implementation
2024-06-16 Power limit implementation
2024-06-22 Bugfixes and improvements for WiFi reconnect and search in UI
    [Webinterface.h]
2024-09-25 Redesign temperature adjustment
2024-09-26 Merged temperature and power limit tabs
2024-09-27 Adjust description and default value of manual temperature output
2024-09-27 Removed toggle button from power area, `enabled` is now defined by the start and end temperature
2024-09-27 Changed temperature adjustment from temperature value to offset
2024-09-27 Changed temperature inputs to one decimal place
2024-09-27 Add target output temperature inside webinterface
2024-09-28 Memory optimization by redesign system and WiFi info labels
    [Webinterface.h]
2024-09-28 Bugfix value key for power adjustment and temperature offset
2024-09-28 Improved UI target temperature update
2024-09-29 Update readme and add excel spreadsheet with charts, calculations and measurements
    [TestsAndCharts.xlsx]
2024-09-29 Add timestamp to Weather API temperature
2024-09-30 Implement invalid WiFi credental handling to switch back to AP mode instead of reconnect.
2024-09-30 Fixed racing condition that lead into invalid WiFi credentials if no return was pressed before click on the save button
    [Webinterface.h]
2024-10-03 Split failover output into input and add setting do define if Weather API should be preferred
    [main.cpp]
2024-10-04 Add missing GND pulldown resistor for the digital potentiometer insdide drawings
    [TCapChamp.fzz, TCapChamp_Failover.fzz]
2024-10-04 Add relay type to readme
2024-10-06 Update documentation
    [TCapChamp_Failover.fzz]
2024-10-06 Update failover drawing
    [TCapChamp_Failover.fzz]
